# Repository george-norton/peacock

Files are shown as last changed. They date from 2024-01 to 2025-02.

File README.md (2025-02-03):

# Peacock

Peacock is an RP2040 powered trackpad running QMK. It features an integrated Microchip MaxTouch sensor IC which is connected to a 7" capacitive sensor. I also designed some little trackpads which you can integrate into your own keyboards, see [Procyon](https://github.com/george-norton/procyon).

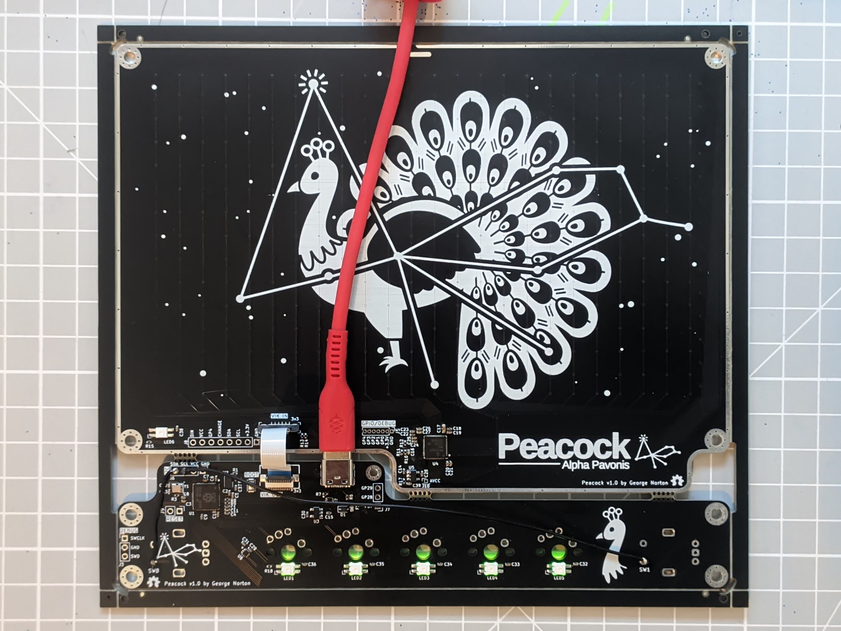
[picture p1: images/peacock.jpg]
Peacock PCB


The [Ploopy trackpad](https://ploopy.co/trackpad/) is like a more polished Peacock, with a higher resolution sensor. It runs code build from the same QMK/ZMK branches, and is easier to buy.

## Features
- Fully PCBA, this other than switches and encoders, this board is designed to be fully factory assembled.
- Integrated RP2040 controller, no need to a separate controller.
- 7 inch 16:9 capacitive sensor.
- 5 Choc/MX switches and 2 EC11/EC12 encoders.
- A [VIK](https://github.com/sadekbaroudi/vik) connection between the controller and sensor board.

## But how does it work?
The capacitive sensing IC is wired to a grid of diamond shaped electrodes. The diamonds are connected to form rows and columns. The IC scans the matrix by
applying a small voltage to the rows in turn, and then measuring voltage on the columns. Any conductive objects nearby (like your finger) will distrupt the
electrical field and can be detected.

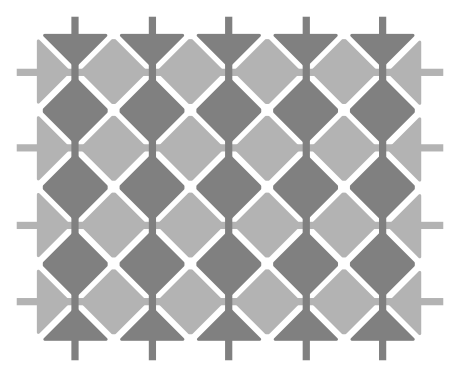
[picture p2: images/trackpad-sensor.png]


## Sensor capabilities
The mXT336UD-MAU002 sensor IC used in this design is in fact a touchscreen controller rather than a trackpad controller. I have chosen to use a touchscreen
controller as they tend to be designed for much larger sensor areas than touchpad controller. This sensor can:
- Detect 10 concurrent touch events.
- Can support both mutual capacitance and self capacitance measurements.
- Has integrated signal processing capabilities to reduce noise, reject large touches (grip or palms) etc..
- Can be configured as a digitizer, or an array of up to 16 buttons.
- The sensor also supports a passive stylus, although the electrodes in Peacock are larger than the recommended size, so this may not perform well.

## Software support
Currently there are experimental QMK and ZMK branches with Peacock support.

The [QMK multitouch_experiment branch](https://github.com/george-norton/qmk_firmware/tree/multitouch_experiment) exteneds the QMK digitizer feature to implement real trackpad support. On this branch, the MaxTouch driver reports 5 separate finger positions to the host and it detects gestures. You should get all the same gesture support you would expect from a modern trackpad. This branch is a large changeset which will likely take some time to get merged into QMK. There are some [pre-built QMK firmware images in my userspace](https://github.com/george-norton/qmk_userspace/releases/tag/latest).

The [ZMK Maxtouch module](https://github.com/george-norton/maxtouch-zephyr-module) builds against Petes [feat/pointers-move-scroll-ptp](https://github.com/petejohanson/zmk/tree/feat/pointers-move-scroll-ptp) ZMK branch. It is currently missing LED support, and fallback to mouse emulation (so no MacOS support).

## Sensor tuning
The sensor sensitivity may require tuning depending on the type of surface you use on your build. This can be done by adjusting the touch threshold, and
if required the transmit gain. If your sensor is not detecting touches well, reduce the touch threshold. If your sensor is jittery, or is detecting spurious touches increase the touch threshold, or if there is any ungrounded metal by the sensor, move it. Increasing the transmit gain will require a larger touch threshold, but it should enable you to use thicker overlays and it will give you more room to adjust the touch threshold.

The mouse emulation gestures are implemented in software, they rely on various parameters that can be tuned by defining macros.

If you flash the QMK debug firmware, you can use the [Maxtouch debug](https://github.com/george-norton/maxtouch-debug) tool to adjust the sensor tuning in real time and see how it works.

## BOM
To build a Peacock you will need:
- Factory assembled PCBs (from, for example JLCPCB).
- 5 Choc v1 or MX switches.
- 5 keycaps.
- 2 Encoders (ec11/ec12).
- 2 Encoder knobs.
- 1 Type-A 12P 0.5 mm pitch FFC cable (ideally around 5cm long) [aliexpress](https://www.aliexpress.com/item/1005004140412156.html).
- [A 3D printed case](case/) and its mounting fixtures.
- Some sort of nice feeling insulating surface to put over the sensor, for example sticky vinyl wrap or acrylic. Ideally this should not have any air gaps, so FDM printed surfaces should be printed with 100% infill. If the surface is too thin the trackpad will not perform well, multiple layers of vinyl may be required.
- 4 rubber bumpons.

## PCB ordering guide
Use the gerbers files in the releases, most options are not critical although a thicker PCB is probably best so it does not flex too much when you press against the sensor.
I have tested with 1.6mm thickness, lead free HASL from JLCPCB.

The sensor IC is not available from LCSC, you will need to use JLCPCB's global parts sourcing service to order chips from Digikey, the digikey part number is 150-ATMXT336UD-MAU002-ND, expect a lead time of 1-2 weeks. You may also find the flash memory and LED parts go in and out of stock, so it might also be worth preordering those. The LEDs are optional, if the are not available you can always hand solder some at a later time.

You can see the correct part orientation here, when ordering ensure that all parts are correctly rotated:

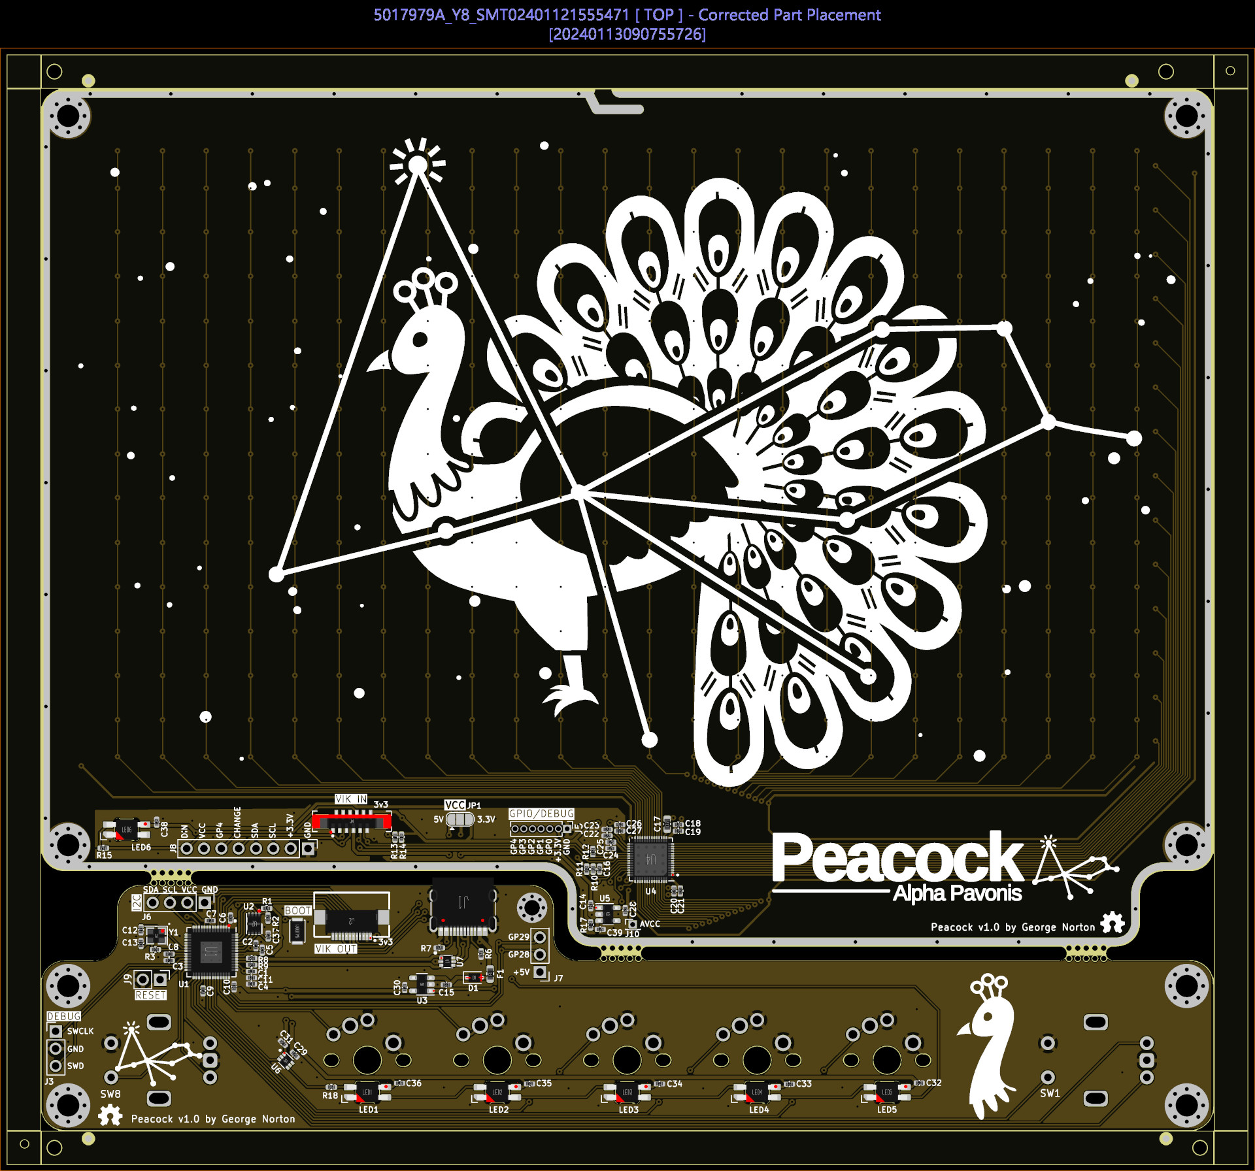
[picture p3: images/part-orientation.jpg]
Part orientation


The v1.0 release has been tested and it works, but there is an issue with the I2C pin allocation. As a result it requires two additional bodge wires, and the encoder switches will not work.

The v1.01 release has the issue fixed, you should order this version.

## Assembly guide

Assembly is simple as the majority of the work is done by the manufacturer. You will need to:

- Remove the edge rails by breaking them off with a pair of pliers, then cut or break the mousebites to separate the two PCBs.

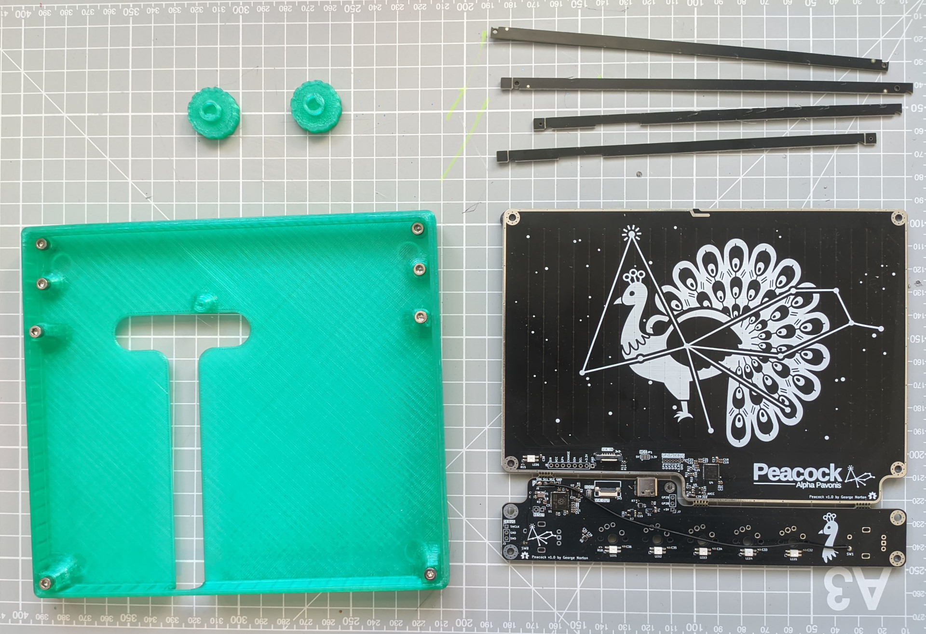
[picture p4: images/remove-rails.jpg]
Remove the edge rails


- Test your PCB. Plug it in and hopefully you will see a new mass storage device. Drag and drop a firmware (uf2) file to flash it. If sucessfull, the LEDs should light up.
- Solder 5 MX/Choc switches.
- Solder 2 EC11/EC12 encoders.

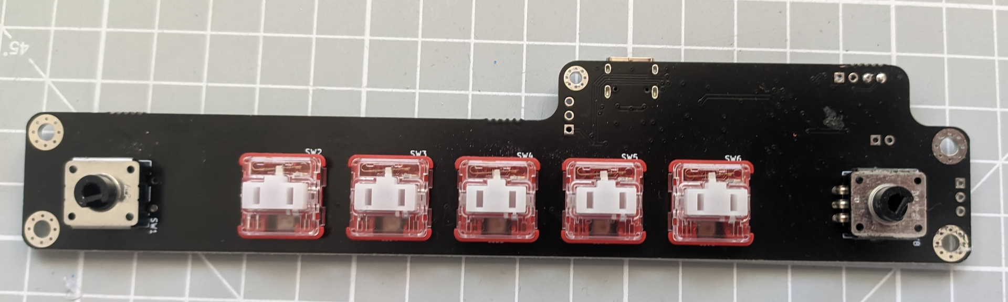
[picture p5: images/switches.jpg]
Solder the switches


- Connect both boards together using the FFC cable, the black parts of the connector can be opened to enable you to insert the cable.

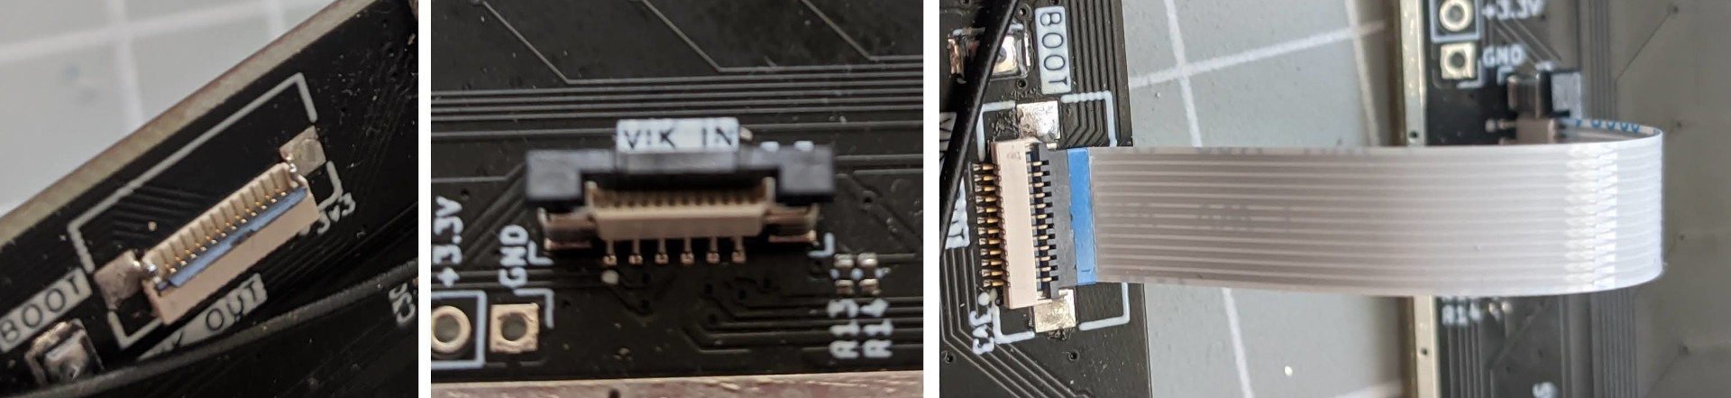
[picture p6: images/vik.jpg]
Connect the VIK cable


- Use a thread tapping tool to create threads in the case.
- Place the boards into the case.
- Screw it in with 8xM3 6mm screws and optionally 1xM2 6mm screw near the USB port.
- Stick your surface to the sensor area. The surface is critical to the performance of the trackpad, without a surface you will likley get no movement at all. Depending on its thickness, a single piece of vinyl will likely be insufficient for the trackpad to track well, a two or three layers will work much better. I noticed that some battery powered USB hosts require additional surface thickness to track multiple fingers well.

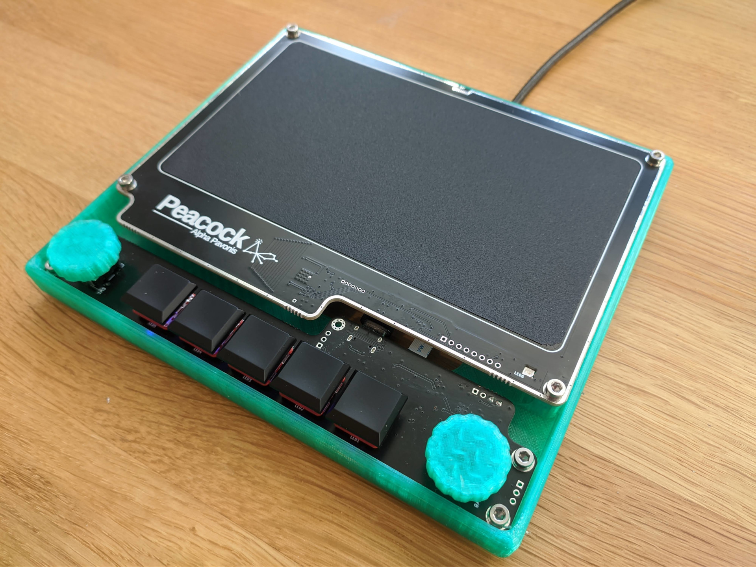
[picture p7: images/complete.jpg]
The completed build


If you build a Peacock, please post a picture in the [show and tell](https://github.com/george-norton/peacock/discussions/categories/show-and-tell).

## Firmware

Peacock support has not yet been merged back to QMK. You can find a branch with pointing device support [here](https://github.com/george-norton/qmk_firmware/tree/peacock) or the multitouch branch [here](https://github.com/george-norton/qmk_firmware/tree/multitouch_experiment) Note, this branch currently does not work with MacOS.

## VIK support

This trackpad is a VIK device, so you should be able to discard the controller portion of the build and wire the trackpad directly to a different VIK enabled controller (such as those sold by fingerpunch and splitkb). You could also replace the controller board with one of your own design.

## VIK certification

Trackpad module

| Category | Classification | Response |
| --- | --- | --- |
| FPC connector | Required | :heavy_check_mark: |
| Breakout pins | Recommended | :heavy_check_mark: |
| Uses: SPI | Optional | :x: |
| SPI used for SPI only | Strongly recommended | N/A |
| Uses: I2C | Optional | :heavy_check_mark: |
| I2C used for I2C only | Strongly Recommended | :heavy_check_mark: |
| I2C pull ups | Required | 3.3k |
| Uses: RGB | Optional | :x: |
| Uses: Extra GPIO 1 | Optional | :heavy_check_mark: |
| Uses: Extra GPIO 2 | Optional | :x: |
| Standard PCB Size/Mount | Strongly recommended | :x: |

Peacock controller

| Category | Classification | Response |
| ---  | --- | --- |
| FPC connector | Required | :heavy_check_mark: |
| Breakout pins | Recommended | :heavy_check_mark: |
| Supplies: SPI | Required | :heavy_check_mark: |
| Supplies: I2C | Required | :heavy_check_mark: |
| I2C on main PCB | Discouraged | :x: |
| I2C pull ups | Informative | N/A |
| Supplies: RGB | Required | :heavy_check_mark: |
| Supplies: Extra GPIO 1 | Required | Analog/Digital |
| Supplies: Extra GPIO 2 | Required | Analog/Digital |

## Schematic

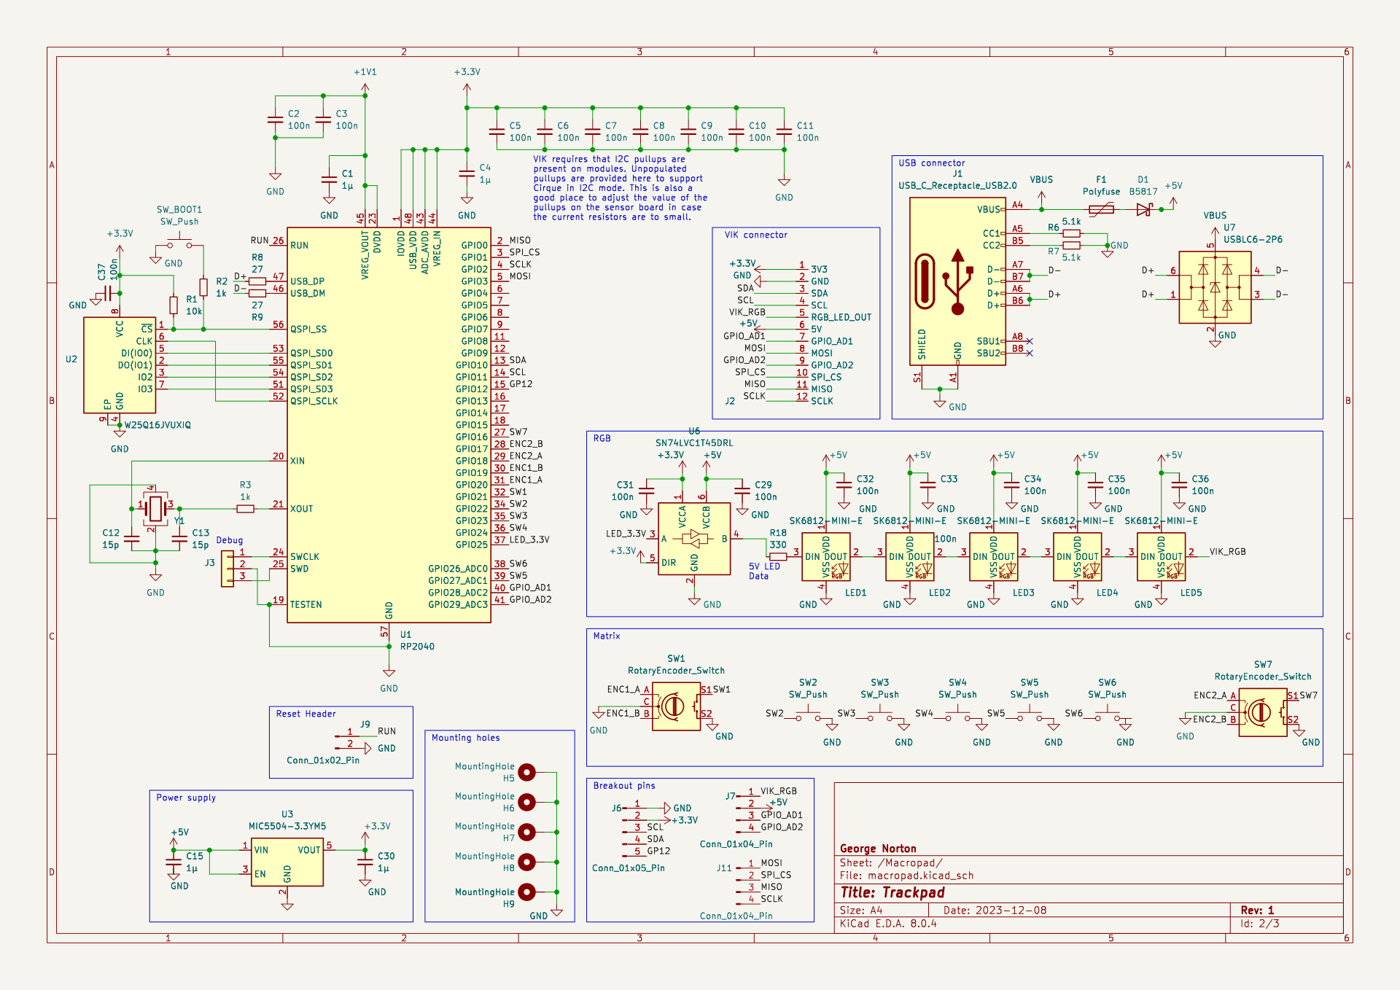
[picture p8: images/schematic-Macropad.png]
Macropad

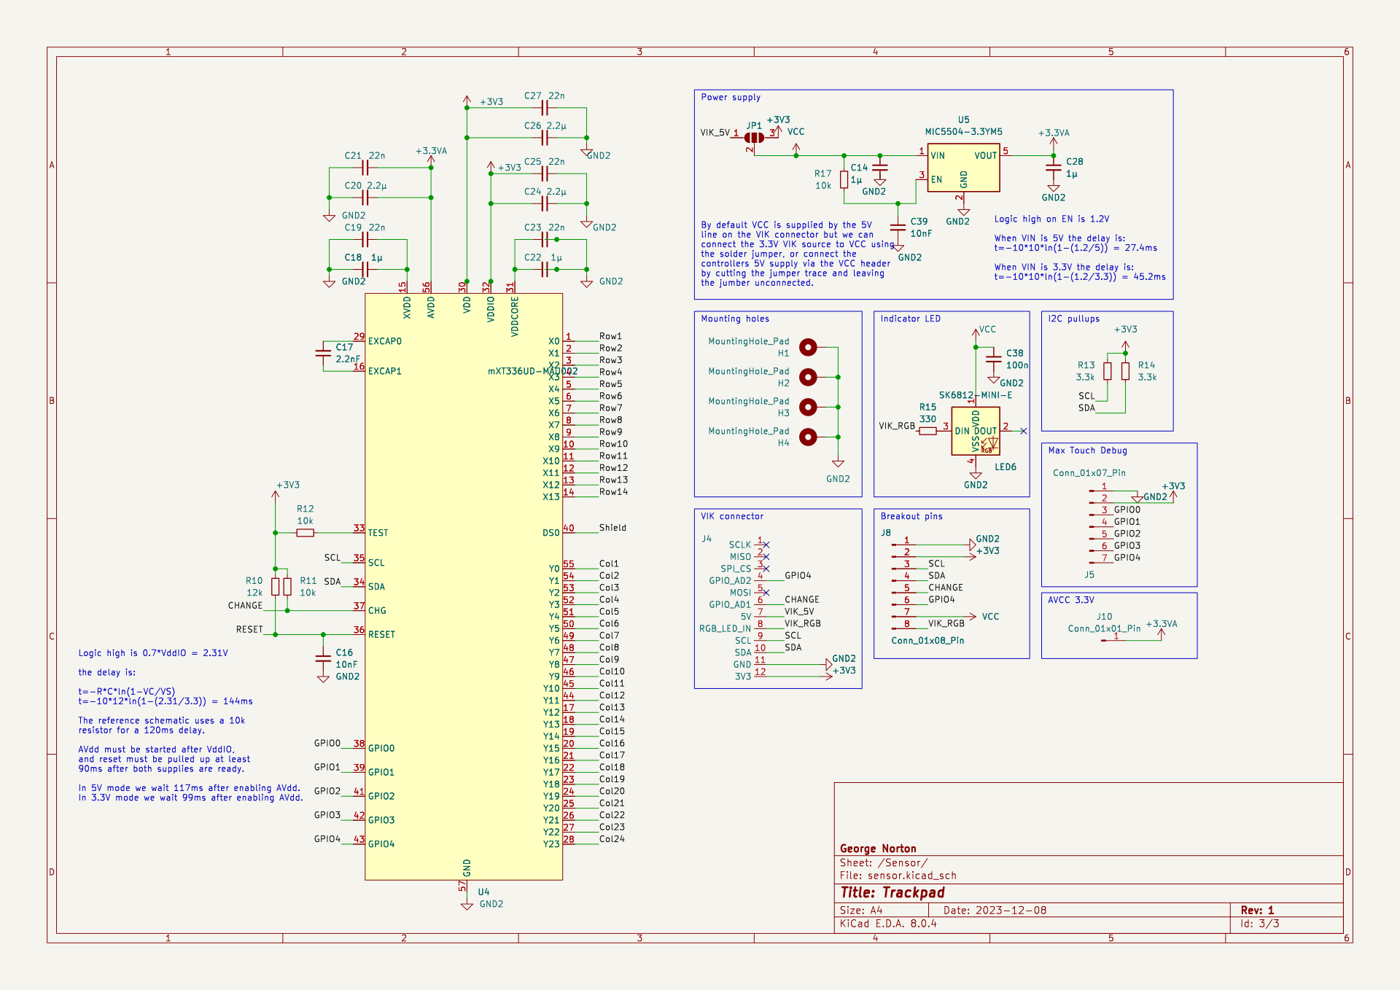
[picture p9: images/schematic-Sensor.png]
Sensor


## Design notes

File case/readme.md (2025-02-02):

## Peacock Trackpad Case by bomtarnes ([keyboard-magpie](https://github.com/keyboard-magpie/))

Peacock low case
Included are STL and STEP files, intended for FDM 3D printing.

Also included are DXF and SVG files intended as a template for making a trackpad overlay (e.g. from Self adhesive vinyl).

The case is designed for m3 hardware in the corners- I used m3x6mm. There is 1 spot for an m2x6mm screw in the centre of the macropad.

Optionally, you can use longer m3 bolts to tilt the back of the case up for comfort.

Additionally files with a 5 degree tilt applied to the base of the case have also been provided for better ergonomics. 

Peacock 5 Deg Case

Peacock low case fusion 360 view

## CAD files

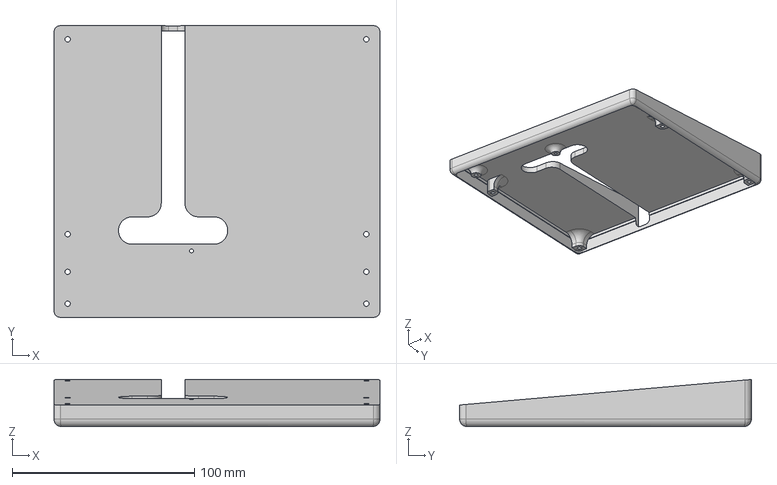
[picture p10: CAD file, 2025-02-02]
case/peacock-low-case-v5-5deg-tilt.step
179.0 x 160.2 x 25.8 mm

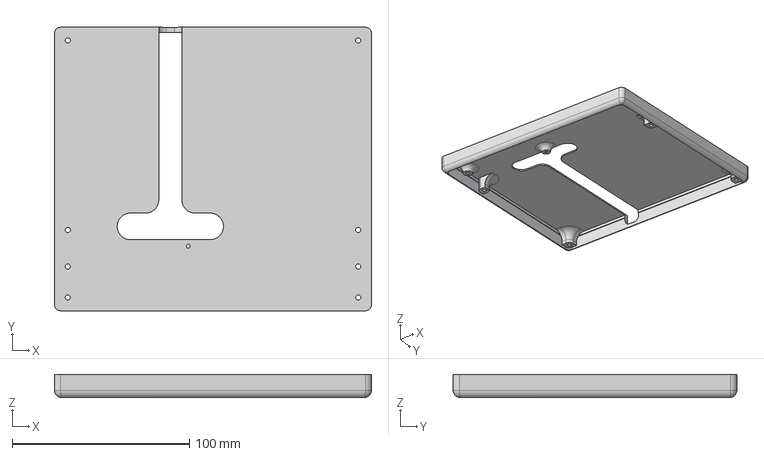
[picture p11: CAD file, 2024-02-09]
case/peacock-low-case-v5.step
179.0 x 160.2 x 13.0 mm

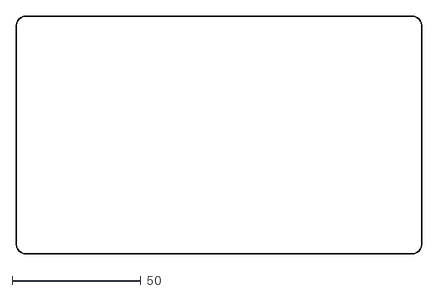
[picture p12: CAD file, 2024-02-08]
case/trackpad-overlay-template.dxf
157.6 x 92.4

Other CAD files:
case/peacock-low-case-v5-5deg-tilt.stl
case/peacock-low-case-v5.stl

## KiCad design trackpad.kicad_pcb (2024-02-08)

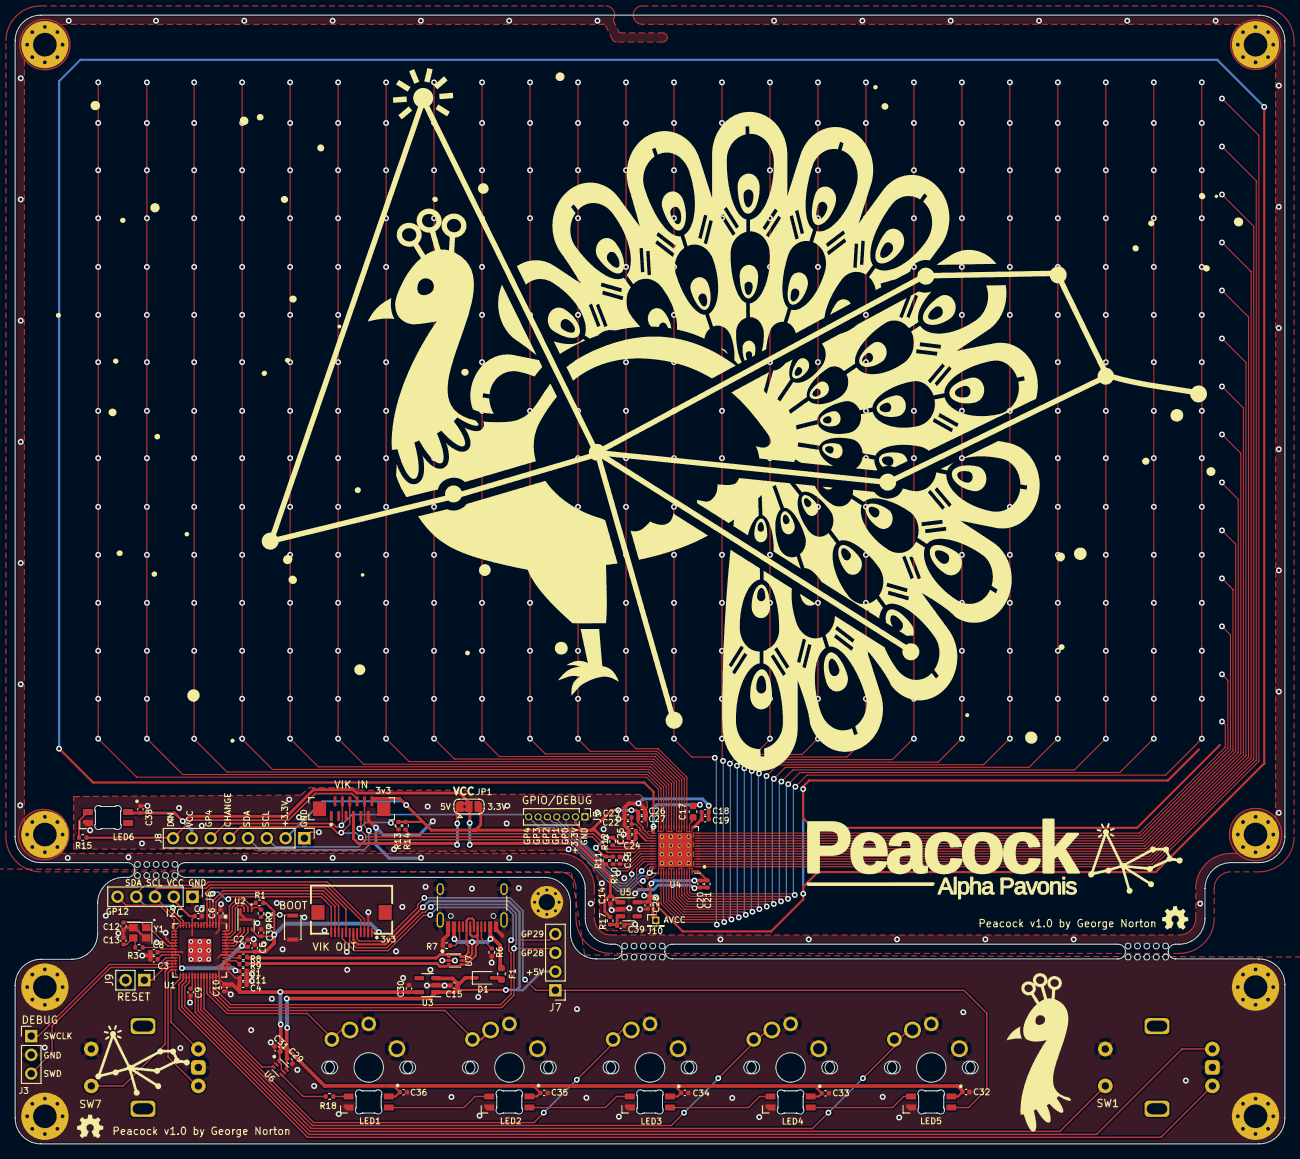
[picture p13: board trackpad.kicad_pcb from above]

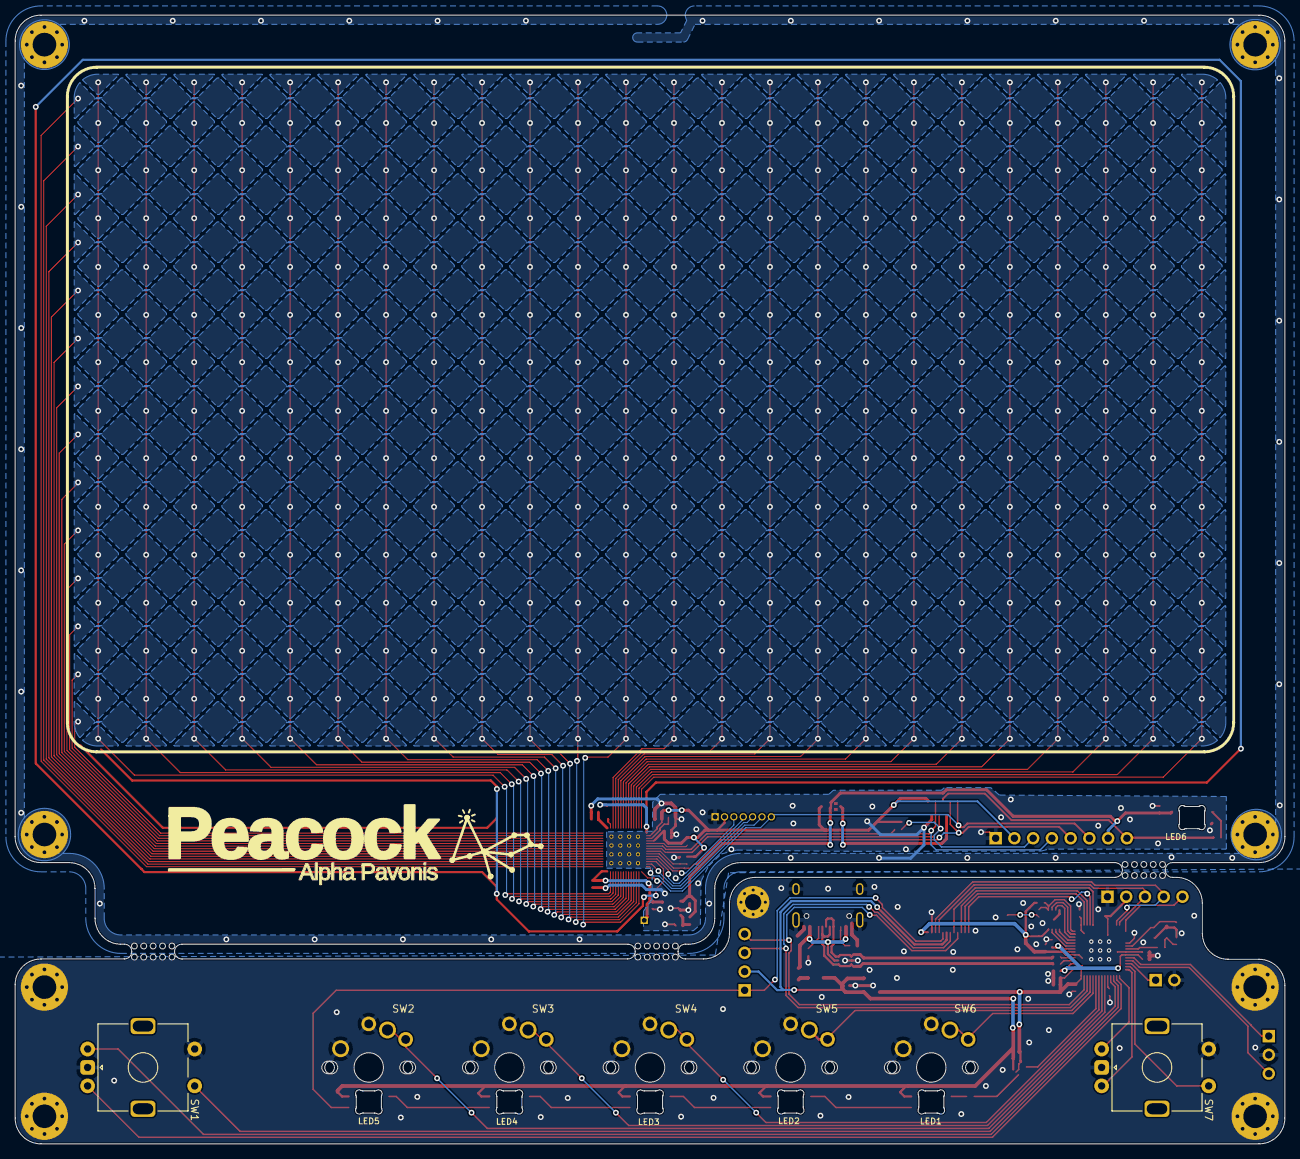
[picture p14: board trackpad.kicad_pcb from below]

Board: 2 copper layers, 172.0 x 152.9 mm, 98 parts (7 on the bottom side), 75 nets.

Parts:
C1, C4, C14, C15, C18, C22, C28, C30: 1µ; C_0402_1005Metric
C2, C3, C5, C6, C7, C8, C9, C10, C11, C29, C31, C32, C33, C34, C35, C36, C37, C38: 100n; C_0402_1005Metric
C12, C13: 15p; C_0402_1005Metric
C16, C39: 10nF; C_0402_1005Metric
C17: 2.2nF; C_0603_1608Metric
C19, C21, C23, C25, C27: 22n; C_0402_1005Metric
C20, C24, C26: 2.2µ; C_0402_1005Metric
D1: B5817; D_SOD-323
F1: Polyfuse; Fuse_0603_1608Metric
H1, H2, H3, H4: MountingHole_Pad; MountingHole_3.2mm_M3_Pad_Via
H5, H7, H8, H9: MountingHole; MountingHole_3.2mm_M3_Pad_Via
H6: MountingHole; MountingHole_2.2mm_M2_Pad_Via
J1: USB_C_Receptacle_USB2.0; USB_C_Receptacle_HRO_TYPE-C-31-M-12
J2: vik-keyboard-connector-horizontal
J3: Conn_01x03; PinHeader_1x03_P2.54mm_Vertical
J4: vik-module-connector-vertical
J5: Conn_01x07_Pin; PinHeader_1x07_P1.27mm_Vertical
J6: Conn_01x05_Pin; PinHeader_1x05_P2.54mm_Vertical
J7: Conn_01x04_Pin; PinHeader_1x04_P2.54mm_Vertical
J8: Conn_01x08_Pin; PinHeader_1x08_P2.54mm_Vertical
J9: Conn_01x02_Pin; PinHeader_1x02_P2.54mm_Vertical
J10: Conn_01x01_Pin; PinHeader_1x01_P1.27mm_Vertical
JP1: SolderJumper_3_Open; SolderJumper-3_P1.3mm_Bridged2Bar12_RoundedPad1.0x1.5mm
LED1, LED2, LED3, LED4, LED5, LED6: SK6812-MINI-E; LED_6028R
R1, R11, R12, R17: 10k; R_0402_1005Metric
R2, R3: 1k; R_0402_1005Metric
R6, R7: 5.1k; R_0402_1005Metric
R8, R9: 27; R_0402_1005Metric
R10: 12k; R_0402_1005Metric
R13, R14: 3.3k; R_0402_1005Metric
R15, R18: 330; R_0402_1005Metric
SW1, SW7: RotaryEncoder_Switch; ROT_Alps_EC11E-Switch
SW2, SW3, SW4, SW5, SW6: SW_Push; SW_choc_MxCombo_1u
SW_BOOT1: SW_Push; SW_SPST_CK_KXT3
U1: RP2040; QFN-56-1EP_7x7mm_P0.4mm_EP3.2x3.2mm
U2: W25Q16JVUXIQ; USON-8-1EP_3x2mm_P0.5mm_EP0.25x1.65mm
U3, U5: MIC5504-3.3YM5; SOT-23-5
U4: mXT336UD-MAU002; QFN-56_EP_6x6_Pitch0.35mm
U6: SN74LVC1T45DRL; SN74LVC1T45DRLR
U7: USBLC6-2P6; SOT-666
Y1: Crystal_GND24; Crystal_SMD_2520-4Pin_2.5x2.0mm

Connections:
+1V1: C1.1, C2.1, C3.1, U1.23 (DVDD), U1.45 (VREG_VOUT), U1.50 (DVDD)
+3.3V: C4.1, C5.1, C6.1, C7.1, C8.1, C9.1, C10.1, C11.1, C30.1, C31.1, C37.2, J2.1 (3V3), J6.2, R1.1, U1.1 (IOVDD), U1.10 (IOVDD), U1.22 (IOVDD), U1.33 (IOVDD), U1.42 (IOVDD), U1.43 (ADC_AVDD), U1.44 (VREG_IN), U1.48 (USB_VDD), U1.49 (IOVDD), U2.8 (VCC), U3.5 (VOUT), U6.1 (VCCA), U6.5 (DIR)
+3.3VA: C20.2, C21.2, C28.1, J10.1, U4.56 (AVDD), U5.5 (VOUT)
+3V3: C24.2, C25.2, C26.2, C27.2, J4.12 (3V3), J5.2, J8.2, JP1.3 (B), R10.1, R11.1, R12.1, R13.1, R14.1, U4.30 (VDD), U4.32 (VDDIO)
+5V: C15.1, C29.1, C32.1, C33.1, C34.1, C35.1, C36.1, D1.1 (K), J2.6 (5V), J7.2, LED1.1 (VDD), LED2.1 (VDD), LED3.1 (VDD), LED4.1 (VDD), LED5.1 (VDD), U3.1 (VIN), U3.3 (EN), U6.6 (VCCB)
/Macropad/D+: J1.A6 (D+), J1.B6 (D+), R8.2, U7.1 (I/O1), U7.6 (I/O1)
/Macropad/D-: J1.A7 (D-), J1.B7 (D-), R9.2, U7.3 (I/O2), U7.4 (I/O2)
/Macropad/ENC1_A: SW1.A, U1.31 (GPIO20)
/Macropad/ENC1_B: SW1.B, U1.30 (GPIO19)
/Macropad/ENC2_A: SW7.A, U1.29 (GPIO18)
/Macropad/ENC2_B: SW7.B, U1.28 (GPIO17)
/Macropad/GP12: J6.5, U1.15 (GPIO12)
/Macropad/GPIO_AD1: J2.7 (GPIO_AD1), J7.3, U1.40 (GPIO28_ADC2)
/Macropad/GPIO_AD2: J2.9 (GPIO_AD2), J7.4, U1.41 (GPIO29_ADC3)
/Macropad/LED_3.3V: U1.37 (GPIO25), U6.3 (A)
/Macropad/MISO: J2.11 (MISO), U1.2 (GPIO0)
/Macropad/MOSI: J2.8 (MOSI), U1.5 (GPIO3)
/Macropad/RUN: J9.1, U1.26 (RUN)
/Macropad/SCL: J2.4 (SCL), J6.3, U1.14 (GPIO11)
/Macropad/SCLK: J2.12 (SCLK), U1.4 (GPIO2)
/Macropad/SDA: J2.3 (SDA), J6.4, U1.13 (GPIO10)
/Macropad/SPI_CS: J2.10 (SPI_CS), U1.3 (GPIO1)
/Macropad/SW1: SW1.S1, U1.32 (GPIO21)
/Macropad/SW2: SW2.2, U1.34 (GPIO22)
/Macropad/SW3: SW3.2, U1.35 (GPIO23)
/Macropad/SW4: SW4.2, U1.36 (GPIO24)
/Macropad/SW5: SW5.2, U1.39 (GPIO27_ADC1)
/Macropad/SW6: SW6.2, U1.38 (GPIO26_ADC0)
/Macropad/SW7: SW7.S1, U1.27 (GPIO16)
/Macropad/VIK_RGB: J2.5 (RGB_LED_OUT), J7.1, LED5.2 (DOUT)
/Sensor/CHANGE: J4.6 (GPIO_AD1), J8.5, R11.2, U4.37 (CHG)
/Sensor/GPIO0: J5.3, U4.38 (GPIO0)
/Sensor/GPIO1: J5.4, U4.39 (GPIO1)
/Sensor/GPIO2: J5.5, U4.41 (GPIO2)
/Sensor/GPIO3: J5.6, U4.42 (GPIO3)
/Sensor/GPIO4: J4.4 (GPIO_AD2), J5.7, J8.6, U4.43 (GPIO4)
/Sensor/RESET: C16.1, R10.2, U4.36 (RESET)
/Sensor/SCL: J4.9 (SCL), J8.3, R13.2, U4.35 (SCL)
/Sensor/SDA: J4.10 (SDA), J8.4, R14.2, U4.34 (SDA)
/Sensor/VIK_5V: J4.7 (5V), JP1.1 (A)
/Sensor/VIK_RGB: J4.8 (RGB_LED_IN), J8.8, R15.2
GND: C1.2, C2.2, C3.2, C4.2, C5.2, C6.2, C7.2, C8.2, C9.2, C10.2, C11.2, C12.2, C13.2, C15.2, C29.2, C30.2, C31.2, C32.2, C33.2, C34.2, C35.2, C36.2, C37.1, H5.1, H6.1, H7.1, H8.1, H9.1, J1.A1 (GND), J1.A12 (GND), J1.B1 (GND), J1.B12 (GND), J1.S1 (SHIELD), J2.2 (GND), J3.2, J6.1, J9.2, LED1.4 (VSS), LED2.4 (VSS), LED3.4 (VSS), LED4.4 (VSS), LED5.4 (VSS), R6.2, R7.2, SW1.C, SW1.S2, SW2.1, SW3.1, SW4.1, SW5.1, SW6.1, SW7.C, SW7.S2, SW_BOOT1.1, U1.19 (TESTEN), U1.57 (GND), U2.4 (GND), U2.9 (EP), U3.2 (GND), U6.2 (GND), U7.2 (GND), Y1.2, Y1.4
GND2: C14.2, C16.2, C18.2, C19.2, C20.1, C21.1, C22.1, C23.1, C24.1, C25.1, C26.1, C27.1, C28.2, C38.2, C39.2, H1.1, H2.1, H3.1, H4.1, J4.11 (GND), J5.1, J8.1, LED6.4 (VSS), U4.57 (GND), U5.2 (GND)
unnamed: C13.1, R3.2, Y1.3
unnamed: D1.2 (A), F1.1
unnamed: J1.A5 (CC1), R6.1
unnamed: J1.B5 (CC2), R7.1
unnamed: J3.1, U1.24 (SWCLK)
unnamed: J3.3, U1.25 (SWD)
unnamed: LED1.3 (DIN), R18.1
unnamed: LED1.2 (DOUT), LED2.3 (DIN)
unnamed: LED2.2 (DOUT), LED3.3 (DIN)
unnamed: LED3.2 (DOUT), LED4.3 (DIN)
unnamed: LED4.2 (DOUT), LED5.3 (DIN)
unnamed: LED6.3 (DIN), R15.1
unnamed: R2.1, SW_BOOT1.2
unnamed: U1.52 (QSPI_SCLK), U2.6 (CLK)
unnamed: U1.53 (QSPI_SD0), U2.5 (DI(IO0))
unnamed: U1.55 (QSPI_SD1), U2.2 (DO(IO1))
unnamed: U1.54 (QSPI_SD2), U2.3 (IO2)
unnamed: U1.51 (QSPI_SD3), U2.7 (IO3)
unnamed: R1.2, R2.2, U1.56 (QSPI_SS), U2.1 (~CS)
unnamed: R9.1, U1.46 (USB_DM)
unnamed: R8.1, U1.47 (USB_DP)
unnamed: C12.1, U1.20 (XIN), Y1.1
unnamed: R3.1, U1.21 (XOUT)
unnamed: C17.2, U4.29 (EXCAP0)
unnamed: C17.1, U4.16 (EXCAP1)
unnamed: R12.2, U4.33 (TEST)
unnamed: C22.2, C23.2, U4.31 (VDDCORE)
unnamed: C18.1, C19.1, U4.15 (XVDD)
unnamed: C39.1, R17.2, U5.3 (EN)
unnamed: R18.2, U6.4 (B)
VBUS: F1.2, J1.A4 (VBUS), J1.A9 (VBUS), J1.B4 (VBUS), J1.B9 (VBUS), U7.5 (VBUS)
VCC: C14.1, C38.1, J8.7, JP1.2 (C), LED6.1 (VDD), R17.1, U5.1 (VIN)

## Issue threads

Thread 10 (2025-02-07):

Ali Express link in readme for cable does not work

zunda-arrow, 2025-02-07:
Hello, first I would like to say thank you for making and open sourcing this project. I just ordered my PCBs a few minutes ago 😄

The link in the readme for the ribbon cable does not work. It seems like the listing may have been removed. I would be grateful if you can replace it with another listing. As someone who isn't that knowledgeable about these kinda electronics, Ali Express can be a little hard to search through.

george-norton, 2025-02-08:
Hello, I guess it is a regional thing as the link works fine for me. There are loads of alternatives on AliExpress, you can try:

https://vi.aliexpress.com/item/1005007974671944.html
https://vi.aliexpress.com/item/1005006334783717.html

Just pick the type-a (the connectors are exposed on the same side of the cable at each end), 12P (that's 12 wires), 0.5mm pitch options.

zunda-arrow, 2025-02-08:
Thank you! I think it might be a region thing (maybe they don't ship to my address?). The link will open then go to "no page found" lol.

Closed 2025-02-08.

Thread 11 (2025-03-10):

Having an issue where trackpad freezes

zunda-arrow, 2025-03-10:
Hello, I am having an issue with my peacock trackpad where it sometimes freezes after some time using it. The keys work correctly but the trackpad does not work at all. I am using about 5 layers of vinyl. The trackpad works again if I unplug and replug it. I think if I unplug and replug really really fast, the issue persists but I am not 100% sure. I do no have the two digital encoders soldered. I am using pcb version 1.0.3. I am using the debug firmware from your userspace.
After it freezes, the trackpad still does not work if I touch the back of the pcb which should be a thicker surface.

When opening the maxtouch debug tool when the trackpad is frozen, I get the following kernal panic:
```
arning: `maxtouch-debug` (lib) generated 6 warnings (run `cargo fix --lib -p maxtouch-debug` to apply 3 suggestions)                                                                   
    Finished `dev` profile [unoptimized + debuginfo] target(s) in 0.15s                                                                                                                 
     Running `target/debug/maxtouch-debug`                                                                                                                                              
Found device: George Norton georgen/peacock                                                                                                                                             
thread 'main' panicked at src/lib.rs:391:38:                                                                                                                                            
Failed to read info block.: "Device reported an error (4)"                                                                                                                              
note: run with `RUST_BACKTRACE=1` environment variable to display a backtrace                                                                                                           
thread 'main' panicked at library/core/src/panicking.rs:221:5:                                                                                                                          
panic in a function that cannot unwind                                                                                                                                                  
stack backtrace:                                                                                                                                                                        
   0:     0x5eb3fbf1c455 - std::backtrace_rs::backtrace::libunwind::trace::h649ab3318d3445c5                                                                                            
                               at /rustc/eeb90cda1969383f56a2637cbd3037bdf598841c/library/std/src/../../backtrace/src/backtrace/libunwind.rs:116:5                                      
   1:     0x5eb3fbf1c455 - std::backtrace_rs::backtrace::trace_unsynchronized::hf4bb60c3387150c3                                                                                        
                               at /rustc/eeb90cda1969383f56a2637cbd3037bdf598841c/library/std/src/../../backtrace/src/backtrace/mod.rs:66:5                                             
   2:     0x5eb3fbf1c455 - std::sys::backtrace::_print_fmt::hd9186c800e44bd00                                                                                                           
                               at /rustc/eeb90cda1969383f56a2637cbd3037bdf598841c/library/std/src/sys/backtrace.rs:65:5                                                                 
   3:     0x5eb3fbf1c455 - <std::sys::backtrace::BacktraceLock::print::DisplayBacktrace as core::fmt::Display>::fmt::h1b9dad2a88e955ff                                                  
                               at /rustc/eeb90cda1969383f56a2637cbd3037bdf598841c/library/std/src/sys/backtrace.rs:40:26                                                                
   4:     0x5eb3fbf4429b - core::fmt::rt::Argument::fmt::h351a7824f737a6a0                                                                                                              
                               at /rustc/eeb90cda1969383f56a2637cbd3037bdf598841c/library/core/src/fmt/rt.rs:173:76                                                                     
   5:     0x5eb3fbf4429b - core::fmt::write::h4b5a1270214bc4a7                                                                                                                          
                               at /rustc/eeb90cda1969383f56a2637cbd3037bdf598841c/library/core/src/fmt/mod.rs:1182:21                                                                   
   6:     0x5eb3fbf1963f - std::io::Write::write_fmt::hd04af345a50c312d                                                                                                                 
                               at /rustc/eeb90cda1969383f56a2637cbd3037bdf598841c/library/std/src/io/mod.rs:1827:15                                                                     
   7:     0x5eb3fbf1d8f1 - std::sys::backtrace::BacktraceLock::print::h68d41b51481bce5c                                                                                                 
                               at /rustc/eeb90cda1969383f56a2637cbd3037bdf598841c/library/std/src/sys/backtrace.rs:43:9                                                                 
   8:     0x5eb3fbf1d8f1 - std::panicking::default_hook::{{closure}}::h96ab15e9936be7ed                                                                                                 
                               at /rustc/eeb90cda1969383f56a2637cbd3037bdf598841c/library/std/src/panicking.rs:269:22                                                                   
   9:     0x5eb3fbf1d5cc - std::panicking::default_hook::h3cacb9c27561ad33                                                                                                              
                               at /rustc/eeb90cda1969383f56a2637cbd3037bdf598841c/library/std/src/panicking.rs:296:9                                                                    
  10:     0x5eb3fbf1df51 - std::panicking::rust_panic_with_hook::hfe205f6954b2c97b                                                                                                      
                               at /rustc/eeb90cda1969383f56a2637cbd3037bdf598841c/library/std/src/panicking.rs:800:13                                                                   
  11:     0x5eb3fbf1dd83 - std::panicking::begin_panic_handler::{{closure}}::h6cb44b3a50f28c44                                                                                          
                               at /rustc/eeb90cda1969383f56a2637cbd3037bdf598841c/library/std/src/panicking.rs:667:13                                                                   
  12:     0x5eb3fbf1c919 - std::sys::backtrace::__rust_end_short_backtrace::hf1c1f2a92799bb0e                                                                                           
                               at /rustc/eeb90cda1969383f56a2637cbd3037bdf598841c/library/std/src/sys/backtrace.rs:168:18                                                               
  13:     0x5eb3fbf1da44 - rust_begin_unwind                                                                                                                                            
                               at /rustc/eeb90cda1969383f56a2637cbd3037bdf598841c/library/std/src/panicking.rs:665:5                                                                    
  14:     0x5eb3fac679c5 - core::panicking::panic_nounwind_fmt::runtime::h907a0444fa61a6dc                                                                                              
                               at /rustc/eeb90cda1969383f56a2637cbd3037bdf598841c/library/core/src/panicking.rs:112:18         
  15:     0x5eb3fac679c5 - core::panicking::panic_nounwind_fmt::h4c4dc67d0bbc166c                                                                                                       
                               at /rustc/eeb90cda1969383f56a2637cbd3037bdf598841c/library/core/src/panicking.rs:122:5                                                                   
  16:     0x5eb3fac67a52 - core::panicking::panic_nounwind::hb98133c151c787e4                                                                                                           
                               at /rustc/eeb90cda1969383f56a2637cbd3037bdf598841c/library/core/src/panicking.rs:221:5                                                                   
  17:     0x5eb3fac67c76 - core::panicking::panic_cannot_unwind::he9511e6e72319a3e                                                                                                      
                               at /rustc/eeb90cda1969383f56a2637cbd3037bdf598841c/library/core/src/panicking.rs:309:5                                                                   
  18:     0x5eb3fb405cdc - webkit2gtk::auto::web_context::WebContextExt::register_uri_scheme::callback_func::hbcac3e9deab88496                                                          
                               at /home/jake/.asdf/installs/rust/1.81.0/registry/src/index.crates.io-6f17d22bba15001f/webkit2gtk-2.0.1/src/auto/web_context.rs:534:5                    
  19:     0x7df8ebbb88bc - <unknown>                                                                                                                                                    
  20:     0x7df8ebb44d33 - <unknown>                                                                                                                                                    
  21:     0x7df8ebb11277 - <unknown>                                                                                                                                                    
  22:     0x7df8ebb1106d - <unknown>                                                                                                                                                    
  23:     0x7df8eb669bd7 - <unknown>                                                                                                                                                    
  24:     0x7df8eba36029 - <unknown>                                                                                                                                                    
  25:     0x7df8ebb372d0 - <unknown>                                                                                                                                                    
  26:     0x7df8eba299a0 - <unknown>
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
zunda-arrow, 2025-03-10:
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

Thank you for the suggestions! I dont think I substituted any parts, I am pretty sure JLPCB had everything in stock but I may have made a mistake because I am new to this 😆 I will go try there suggestions.

george-norton, 2025-03-13:
Thanks for the feedback. Out of interest, is your FFC cable 5cm, or did you use a longer one?

zunda-arrow, 2025-03-13:
> Thanks for the feedback. Out of interest, is your FFC cable 5cm, or did you use a longer one?

I used a really long one by accident. I accidentally ordered the wrong one on Ali Express 😆

george-norton, 2025-03-13:
Ok! Hopefully if you get a shorter one you can bump up the I2C speed. Although in reality, you probably won't rlaee much difference between 400Mhz and 1000Mhz unless you start running loads of code in your keymap.

Closed 2025-03-13.

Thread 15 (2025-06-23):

MacOS Support

loadedsith, 2025-06-23:
Hello,

This looks neat, but as a Mac user I can't try it.

What's the status of MacOS support?

Do you need help? What might that entail?

Thanks,
G

loadedsith, 2025-06-23:
Ok, then, if that's the case, I'll order one up and see what I can do. Will let you know when it's assembled :)

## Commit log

2023-12-15 Initial commit of 'peacock'
    [macropad.kicad_sch, sensor.kicad_sch, trackpad.kicad_pcb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]
2023-12-15 Cleanup libraries
    [macropad.kicad_sch, sensor.kicad_sch, trackpad.kicad_sch]
2023-12-20 Switch LDO for a cheaper part.
    [macropad.kicad_sch, sensor.kicad_sch, trackpad.kicad_pcb]
2023-12-22 Move USB port closer to the edge, Additional silkscreen, Add reset header, shrink LDO caps, swap QSPI flash.
    [macropad.kicad_sch, sensor.kicad_sch, trackpad.kicad_pcb]
2024-01-02 Re-route to avoid crossing the USB data lines. Reduced keys to 5 to avoid having to route a long trace around the crystal, swaped key footprint from choc hotswap to mx/choc combined soldered.
    [macropad.kicad_sch, sensor.kicad_sch, trackpad.kicad_pcb]
2024-01-03 Minor cleanups. Made the mounting hole distances round numbers, cleaned up a few traces.
    [macropad.kicad_sch, sensor.kicad_sch, trackpad.kicad_pcb]
2024-01-05 Modify EC11 footprint to allow SMT parts. Add resistors to the LED data lines.
    [macropad.kicad_sch, sensor.kicad_sch, trackpad.kicad_pcb]
2024-01-05 Fix DRC issue and add VCC warning.
    [macropad.kicad_sch, sensor.kicad_sch, trackpad.kicad_pcb]
2024-01-05 Tweak fills.
    [trackpad.kicad_pcb]
2024-01-11 Minor tweaks
    [macropad.kicad_sch, sensor.kicad_sch, trackpad.kicad_pcb]
2024-01-11 Add missing paste on max touch epad.
    [trackpad.kicad_pcb]
2024-01-12 Use encroached vias. Update footprints
    [trackpad.kicad_pcb]
2024-01-12 Modifications before initial order.
    [macropad.kicad_sch, sensor.kicad_sch, trackpad.kicad_pcb]
2024-01-29 Use less offensive colours on the sensor image.
2024-01-29 Simplify sensor diagram.
2024-02-05 initial case files for low version
    [peacock-low-case-v4.step, peacock-low-case-v4.stl]
2024-02-05 add overlay template
    [trackpad-B_Silkscreen.dxf, trackpad-overlay-template.dxf]
2024-02-05 Delete case/trackpad-B_Silkscreen.dxf
    accidental addition.
    [trackpad-B_Silkscreen.dxf]
2024-02-08 correct svg and dxf files for scaling
    [trackpad-overlay-template.dxf]
2024-02-08 update case/readme to reflect all hardware
2024-02-08 add v5 case- improved bolt tolerances
    [peacock-low-case-v5.step, peacock-low-case-v5.stl]
2024-02-08 remove v4 files
    [peacock-low-case-v4.step, peacock-low-case-v4.stl]
2024-02-08 I2C pins were incorrect.
    [macropad.kicad_sch, trackpad.kicad_pcb]
2024-02-08 Fixes for minor issues in the v1.0 PCB.
    [macropad.kicad_sch, sensor.kicad_sch]
2024-02-08 Fixup LSCS part number miss-match between PCB and schematic.
    [sensor.kicad_sch]
2024-02-09 Show part orientation and link to case
2024-02-09 Expand software support and assembly guide.
2024-02-09 v5 case correction
    [peacock-low-case-v5.step, peacock-low-case-v5.stl]
2024-03-21 Fix minor issues reported by JLC, and replace parts which are often out of stock.
    [macropad.kicad_sch, sensor.kicad_sch]
2024-03-22 Swap the VIK connector part for the default, the new part has pin 1 labelled differently
    [macropad.kicad_sch]
2024-03-22 Update the submodules. New VIK vertical silkscreen and LED silkscreen, maybe it will prevent JLC querying the orientation
2024-11-30 Add schematics
2025-01-28 Add Peacock case with 5 deg tilt
    [peacock-low-case-v5-5deg-tilt.step, peacock-low-case-v5-5deg-tilt.stl]
2025-02-02 Add image of the new case type
